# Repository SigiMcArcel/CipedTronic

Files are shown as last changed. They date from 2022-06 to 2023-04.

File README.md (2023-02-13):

#  feasibility study. Bicycle Speedometer
Hardware and software for measuring distance of a bike with a mobil phone.
The needed information will get thru the sine wave of the hub dynamo of the bike.
A hardware converts the sine wave to a TTL signal. 
A microcontroller counts the pulses
The mobil gets the data thru Bluetooth LE
A java app receive the Bluetooth LE data and shows the value on a GUI
The hardware must be simple and small for covering in a bicycle lamp.

#The Application
The microcontroller sends the 

count of pulses (distance), 
the count of pulses per second (velocity)
the count of pulses per second average
the count of pulses per second maximum
The count of pulses will save in the microcontrollers EEPROM

The Android App calculates the informations to Km/h and Km with settings like pulses per revolution and wheel radius,
this data will show in the GUI.

In the first Version i implemented the nordic UART Service and send and receive the data as string.
In the further versions i used a custom service and characteristics to exchange the data.So i spent code and was more comfortable to handle it 

The next idea is to use the standard Bluetooth LE service "Cycling Speed and Cadence" to exchange the data.
So i can use my speedometer with other android Apps.
Therfore i have to reimplement the the pulse measuring.

further steps are :
- Porting the software to a seed XIAO ESP32C3 is lot smaller and has akku load functions
- Combine the hardware with LED Lightning and Supercaps
- extend the android app with "Tours" functionality. So i can set several tours.

##Hardware Komponents
ATMEGA 32u4 Arduino Leonard0
Adafruit nrf80001 breakout
Samsung X-Cover Pro Smartphone Android SDK 30

#Developer Tools
Microchip studio for ATMEGA 32u4
Android studio for Android App developing
LT Spice for developing the Converter Hardware

## Hardware for pulse converting
The big Problem is to handle the voltage on unloaded state.
The voltage can gos up to > 20 Volts.

I'm still looking for a good and sinmplesolution for this problem

##Software
###Microcontroller
Project : CipedTronicMCU
The Software uses fololowing sources:
the nordic nrf80001 sdk
The USB CDC from J. Fiene & J. Romano https://github.com/PennRobotics/acrobot 

USBSerial:
For debugging i implemented a Modul for receive and send string and chars thru the usb interface of the ATMEGA 32u4.
Therfore i'm using the USBDCD source.

Bluetooth LE:
The Atmega 32u4 communicate thru SPI with the Bluetooth LE Breakout.
In the modul BLE.cpp all needed step are implemented for using the breakout.
The nordic sdk includes the necessary functions.
BLE.cpp is written in c++ for compatibility to the nordic sdk.

Evaluate the sine waves of the hub dynamo:
For that i use the counter 1 of the Atmega 32u4. it is count the pulses.
For prevent the overflow after 16 Bit, the software adds the actual counter value to a 32 bit variable and deletes the counter.
Every second the software checks the count of pulses since last call ang gives the count of pulses per second (Counter.c ,Timer.c)

maximum km's:
(Unloaded)
wheel radius = 37 cm, pulses per revolution = 18
circumference per revolution = 2 * 0,00037 kilometers * pi =    0,00232477856 kilometers
pulses per km = 1/0,00232477856 * 18 = 7742 Pulses
or 0,12915436 meters per puls

u32Bit =  4294967295 /7742 = 554761 km. (less than i thought,may be i need a u64Bit Integer)

accuracy:
depends on tire pressure and wight.
Loaded ->
Assumed 4,5 Bar pressure and 70 kg weight a different of 5 mm
circumference per revolution = 2 * 0,000365 kilometers * pi =    0,00229336263 kilometers
pulses per km = 1/0,00229336263 * 18 = 7 848 Pulses
or  0,12740903 meters per pulse									 
unloaded <-> loaded ->
6 Pulses -> 76 cm

almost a metre per kilometre. its a lot !!
But I found a test of gps tracker on Internet. Result : Real distance 5Km , gps tracker 5,14 km.
the speedometer  calculates :  5 km -> 5 * 76 cm = 380 cm. Maybe better.

###Android App
The App is implemented as a Viewmodel Pattern.
The BLE part is implemented fully asynchron. 
Actually the BLE part is written as a singleton class. But it prepared for using as Android service.
The data exchange between class and Viewmodel works with events and livedata.
GUI:
The App consists three Fragments there's is collected as tabs.
Main and Datafragments :
- Shows the velocity and distance
- Resets the counter
Devicefragment:
- Searching and select cipedtronic devices
Settingsfragment:
- Sets wheel raduis and pulses per revolution

classes:
BLEDevice.java : Consist the BLE Stack with all needed functionality.
CipedTronicMCU.java : Opens BLE services,handle characteristics, calculate mcu data
PageViewModel.java : handles data exchange beetween Fragments, starts the MCU/BLE Part

SectionsPagerAdapter.java : Handles Tabs and Fragments
DataFragment.java : The data GUI
DeviceFragment.java : The device search fragment
SettingsFragment.java : The settings fragment

#Branches:
##main
BLE Uart Version of Cipedtronic
##BLENonUart
 the CUstom and standard service

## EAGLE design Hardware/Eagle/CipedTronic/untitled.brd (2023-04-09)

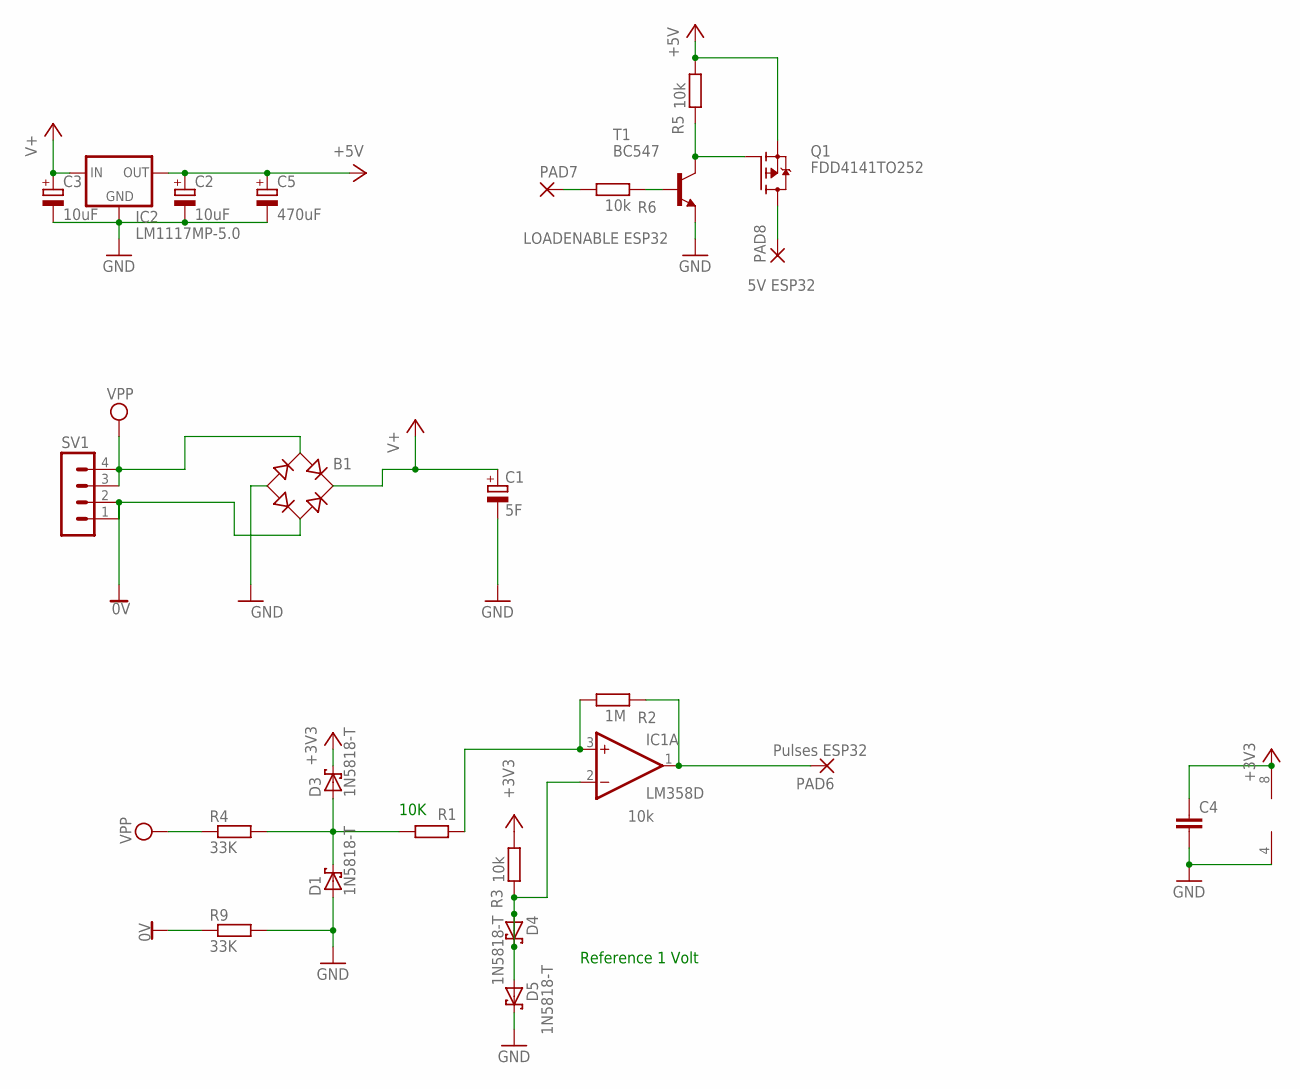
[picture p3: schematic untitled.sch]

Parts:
B1: B-DIL
C1: 5F; E2,5-6E
C2, C3: 10uF; E2,5-6E
C4: C-EU050-024X044; C050-024X044
C5: 470uF; E2,5-6E
D1, D3, D4, D5: 1N5818-T; DO41-7.6
IC1: LM358D; SO08
IC2: LM1117MP-5.0; SOT223
PAD6: Pulses ESP32; 2,15/1,0
PAD7: LOADENABLE ESP32; 2,15/1,0
PAD8: 5V ESP32; 2,15/1,0
Q1: FDD4141TO252; TO252
R1, R3, R5, R6: 10k; 0204V
R2: 1M; 0204V
R4, R9: 33K; 0204V
SV1: MA04-1
T1: BC547; TO92

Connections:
0V: B1.AC2, R9.1, SV1.1, SV1.2
+3V3: B1.+, C1.+, C4.1, D3.C, IC1.8 (V+), R3.1
+5V: C2.+, C5.+, IC2.2 (OUT), IC2.4 (OUT), Q1.2 (S), R5.1
GND: B1.-, C1.-, C2.-, C3.-, C4.2, C5.-, D1.A, D5.C, IC1.4 (V-), IC2.1 (GND), R9.2, T1.1 (E)
unnamed: IC1.1 (OUT), PAD6.1, R2.2
unnamed: PAD7.1, R6.1
unnamed: R6.2, T1.2 (B)
unnamed: IC1.3 (+IN), R1.1, R2.1
unnamed: D4.A, D4.C, D5.A, IC1.2 (-IN), R3.2
unnamed: Q1.1 (G), R5.2, T1.3 (C)
unnamed: PAD8.1, Q1.3 (D)
unnamed: D1.C, D3.A, R1.2, R4.2
V+: C3.+, IC2.3 (IN)
VPP: B1.AC1, R4.1, SV1.3, SV1.4

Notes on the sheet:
10K
Reference 1 Volt

Board: 2 copper layers, 25 parts (0 on the bottom side), 14 nets, no tracks yet.

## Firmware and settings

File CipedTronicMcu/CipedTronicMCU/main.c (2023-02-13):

/* Copyright 2023 Marcel Siegwart
* 
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
* Neither the name of the copyright holders nor the names of
* contributors may be used to endorse or promote products derived
* from this software without specific prior written permission.
* 
* THE SOFTWARE IS PROVIDED "AS IS", WITHOUT WARRANTY OF ANY KIND, 
* EXPRESS OR IMPLIED, INCLUDING BUT NOT LIMITED TO THE WARRANTIES OF MERCHANTABILITY, 
* FITNESS FOR A PARTICULAR PURPOSE AND NONINFRINGEMENT. 
* IN NO EVENT SHALL THE AUTHORS OR COPYRIGHT HOLDERS BE LIABLE FOR ANY CLAIM, 
* DAMAGES OR OTHER LIABILITY, WHETHER IN AN ACTION OF CONTRACT, 
* TORT OR OTHERWISE, ARISING FROM, OUT OF OR IN CONNECTION WITH THE SOFTWARE 
* OR THE USE OR OTHER DEALINGS IN THE SOFTWARE.
*/

/*
 * main.c
 *
 * Main Entry
 * Created: 18.04.2022 13:50:13
 *  Author: Siegwart
 */ 
#include <avr/io.h>
#include <avr/interrupt.h>
#include "Platform/Timer.h"
#include "Platform/GPIO.h"
#include "Platform/Counter.h"
#include "Platform/Serial.h"
#include "CipedTronic/BLE.h"
#include <stdio.h>
#include <stdlib.h>
#include <string.h>


#define SOFTWAREVERSION "00.00.42"
#define DEVICENAME "CIPBLA"

//notification intervall
static volatile uint32_t _LastTimerTick = 0;
static volatile uint32_t _Delay = 0;
static volatile uint32_t _Control = 0;
static volatile uint32_t _Test = 0;

//Speedometer data
static uint32_t _Counter = 0;
static uint32_t _CounterPerSecond = 0;
static uint32_t _CounterPerSecondAvg = 0;
static uint32_t _CounterPerSecondMax = 0;

static void BLERxCallback(uint8_t characteristic, uint32_t value);


//BLE stack callback
static void BLERxCallback(uint8_t characteristic, uint32_t value)
{
	SerialPuts("BLERxCallback ");
	SerialPutsLong(characteristic);
	SerialPuts(" ");
	SerialPutsLong(value);
	SerialPuts("\r\n");
	switch(characteristic)
	{
		//sets Counter Per Second maximum (for future use, multiple tours)
		case PIPE_CIPEDTRONIC_BIKE_SERVICE_MAXIMUM_VELOCITY_RX:
		{
			CounterSetMaxCounterPerSecond(value);
			break;
		}
		//sets Counter Per Second average (for future use, multiple tours)
		case PIPE_CIPEDTRONIC_BIKE_SERVICE_AVERAGE_VELOCITY_RX:
		{
			CounterSetAvgCounterPerSecond(value);
			break;
		}
		//sets Distance (for future use, multiple tours)
		case PIPE_CIPEDTRONIC_BIKE_SERVICE_DISTANCE_RX:
		{
			CounterSetCounter(value);
			break;
		}
		
		//Handles control value
		case PIPE_CIPEDTRONIC_BIKE_SERVICE_CONTROL_RX:
		{
			_Control = value;
			SerialPuts("PIPE_CIPEDTRONIC_BIKE_SERVICE_CONTROL_RX 0x");
			SerialPutsHex32(_Control);
			SerialPuts("\r\n");
			//resets all Counters
			if((_Control & 0x0000001) > 0)
			{
				SerialPuts("Counter Reset\r\n");
				CounterResetCounter();
			}
			_Control = 0;
			break;
		}
	}
}

int main (void)
{
	//initialize mcu hardware
	GPIOInit();
	TimerInit();
	CounterInit();
	USBSerialInit();

	GPIOSetDirection(5,&DDRD,GPIO_DIR_OUT);//tx
	GPIOSetDirection(0,&DDRB,GPIO_DIR_OUT);//rx
	GPIOSetDirection(7,&DDRC,GPIO_DIR_OUT);//PW led
	
	//register Notification Values
	BLERegisterNotificationValue(PIPE_CIPEDTRONIC_BIKE_SERVICE_VELOCITY_TX,&_CounterPerSecond);
	BLERegisterNotificationValue(PIPE_CIPEDTRONIC_BIKE_SERVICE_MAXIMUM_VELOCITY_TX,&_CounterPerSecondMax);
	BLERegisterNotificationValue(PIPE_CIPEDTRONIC_BIKE_SERVICE_AVERAGE_VELOCITY_TX,&_CounterPerSecondAvg);
	BLERegisterNotificationValue(PIPE_CIPEDTRONIC_BIKE_SERVICE_DISTANCE_TX,&_Counter);
	BLEInit(0,100,DEVICENAME,SOFTWAREVERSION,BLERxCallback);
	
	while(1)
	{
		uint32_t tick = TimerGetTick();
		uint32_t diff = tick - _LastTimerTick;
		CounterHandler();//Process Counters
		BLEProcess(); //Process BLE
		if(diff >= 500)
		{
			//Toggle LED
			GPIOToggle(7,&PORTC);
			//Update counter values
			_CounterPerSecond = CounterGetCounterPerSecond();
			_CounterPerSecondMax = CounterGetMaxCounterPerSecond();
			_CounterPerSecondAvg = CounterGetAvgCounterPerSecond();
			_Counter = CounterGetCounter();
			//Send registered notification
			BLESendNotification();
			_LastTimerTick = tick;
		}
		
	}
}

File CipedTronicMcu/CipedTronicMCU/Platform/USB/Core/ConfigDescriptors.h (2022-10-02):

/*
             LUFA Library
     Copyright (C) Dean Camera, 2015.

  dean [at] fourwalledcubicle [dot] com
           www.lufa-lib.org
*/

/*
  Copyright 2015  Dean Camera (dean [at] fourwalledcubicle [dot] com)

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
  The author disclaims all warranties with regard to this
  software, including all implied warranties of merchantability
  and fitness.  In no event shall the author be liable for any
  special, indirect or consequential damages or any damages
  whatsoever resulting from loss of use, data or profits, whether
  in an action of contract, negligence or other tortious action,
  arising out of or in connection with the use or performance of
  this software.
*/

/** \file
 *  \brief USB Configuration Descriptor definitions.
 *  \copydetails Group_ConfigDescriptorParser
 *
 *  \note This file should not be included directly. It is automatically included as needed by the USB driver
 *        dispatch header located in LUFA/Drivers/USB/USB.h.
 */

/** \ingroup Group_StdDescriptors
 *  \defgroup Group_ConfigDescriptorParser Configuration Descriptor Parser
 *  \brief USB Configuration Descriptor definitions.
 *
 *  This section of the library gives a friendly API which can be used in host applications to easily
 *  parse an attached device's configuration descriptor so that endpoint, interface and other descriptor
 *  data can be extracted and used as needed.
 *
 *  @{
 */

#ifndef __CONFIGDESCRIPTORS_H__
#define __CONFIGDESCRIPTORS_H__

	/* Includes: */
		#include "Platform/USB/Common/Common.h"
		#include "USBMode.h"
		#include "HostStandardReq.h"
		#include "StdDescriptors.h"

	/* Enable C linkage for C++ Compilers: */
		#if defined(__cplusplus)
			extern "C" {
		#endif

	/* Preprocessor Checks: */
		#if !defined(__INCLUDE_FROM_USB_DRIVER)
			#error Do not include this file directly. Include LUFA/Drivers/USB/USB.h instead.
		#endif

	/* Public Interface - May be used in end-application: */
		/* Macros: */
			/** Casts a pointer to a descriptor inside the configuration descriptor into a pointer to the given
			 *  descriptor type.
			 *
			 *  Usage Example:
			 *  \code
			 *  uint8_t* CurrDescriptor = &ConfigDescriptor[0]; // Pointing to the configuration header
			 *  USB_Descriptor_Configuration_Header_t* ConfigHeaderPtr = DESCRIPTOR_PCAST(CurrDescriptor,
			 *                                                           USB_Descriptor_Configuration_Header_t);
			 *
			 *  // Can now access elements of the configuration header struct using the -> indirection operator
			 *  \endcode
			 */
			#define DESCRIPTOR_PCAST(DescriptorPtr, Type) ((Type*)(DescriptorPtr))

			/** Casts a pointer to a descriptor inside the configuration descriptor into the given descriptor
			 *  type (as an actual struct instance rather than a pointer to a struct).
			 *
			 *  Usage Example:
			 *  \code
			 *  uint8_t* CurrDescriptor = &ConfigDescriptor[0]; // Pointing to the configuration header
			 *  USB_Descriptor_Configuration_Header_t ConfigHeader = DESCRIPTOR_CAST(CurrDescriptor,
			 *                                                       USB_Descriptor_Configuration_Header_t);
			 *
			 *  // Can now access elements of the configuration header struct using the . operator
			 *  \endcode
			 */
			#define DESCRIPTOR_CAST(DescriptorPtr, Type)  (*DESCRIPTOR_PCAST(DescriptorPtr, Type))

			/** Returns the descriptor's type, expressed as the 8-bit type value in the header of the descriptor.
			 *  This value's meaning depends on the descriptor's placement in the descriptor, but standard type
			 *  values can be accessed in the \ref USB_DescriptorTypes_t enum.
			 */
			#define DESCRIPTOR_TYPE(DescriptorPtr)    DESCRIPTOR_PCAST(DescriptorPtr, USB_Descriptor_Header_t)->Type

			/** Returns the descriptor's size, expressed as the 8-bit value indicating the number of bytes. */
			#define DESCRIPTOR_SIZE(DescriptorPtr)    DESCRIPTOR_PCAST(DescriptorPtr, USB_Descriptor_Header_t)->Size

		/* Type Defines: */
			/** Type define for a Configuration Descriptor comparator function (function taking a pointer to an array
			 *  of type void, returning a uint8_t value).
			 *
			 *  \see \ref USB_GetNextDescriptorComp function for more details.
			 */
			typedef uint8_t (* ConfigComparatorPtr_t)(void*);
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

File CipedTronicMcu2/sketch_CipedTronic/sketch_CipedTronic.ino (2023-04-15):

#include "Ciped.h"
#include "CipedService.h"
#include <BLEDevice.h>
#include <BLEServer.h>

using namespace CipedTronic;
BLEServer* _Server;
Ciped* _Ciped =  NULL;
CipedService* _CipedService = NULL;
uint32_t _LastState = 0;



class CipedControlPointEvents: public CipedTronic::CipedServiceEvents
{
public:
  uint8_t ControlPointWritten(CipedTronic::CipedControlPointOpCodes_e opCode,CipedControlPoint* data)
  {
    if(_Ciped == NULL)
    {
      return (uint8_t)CipedTronic::CipedControlPointResultCodes_e::OperationFailed;
    }
    
    switch(opCode)
    {
      
      case CipedTronic::CipedControlPointOpCodes_e::SetFlags:
      {
        Serial.printf("SetFlags 0x%x\r\n",data->Parameter);
        _Ciped->setFlags(data->Parameter);
        
        return (uint8_t)CipedTronic::CipedControlPointResultCodes_e::Success;
      } 

       case CipedTronic::CipedControlPointOpCodes_e::GetFlags:
      {
  
        data->Parameter = _Ciped->getFlags();
        Serial.printf("GetFlags 0x%x\r\n",data->Parameter);
        return (uint8_t)CipedTronic::CipedControlPointResultCodes_e::Success;
      } 

      case CipedTronic::CipedControlPointOpCodes_e::ResetCounter:
      {
         Serial.printf("ResetCounter 0x%x\r\n",data->Parameter);
        _Ciped->clear();
       return (uint8_t)CipedTronic::CipedControlPointResultCodes_e::Success;
      } 
      
      case CipedTronic::CipedControlPointOpCodes_e::AlarmEnable:
      {
         Serial.printf("AlarmEnable 0x%x\r\n",data->Parameter);
        _Ciped->enableAlarm((bool)data->Parameter);
       return (uint8_t)CipedTronic::CipedControlPointResultCodes_e::Success;
      } 
    }
    
  }
};

void setup() {
  Serial.begin(115200);
  Serial.println("Starting BLE work!");
  

  BLEDevice::init("CIPED");
  _Server = BLEDevice::createServer();
  if(_Server != NULL)
  {
    _Ciped = new Ciped();
    _Ciped->begin();
    _CipedService = new CipedService(_Server,new CipedControlPointEvents());
    _CipedService->start();
  }  

}
 
void loop() {
  CipedBikeData data = {0};
  CipedInfo info = {0};
  uint32_t state = 0;  
  _Ciped->process();
  _Ciped->getCipedBikeData(&data);
  _Ciped->getCipedBikeInfo(&info);
  
  _CipedService->setCipedData(&data);
  _CipedService->setCipedInfo(&info);
  _CipedService->process();
}

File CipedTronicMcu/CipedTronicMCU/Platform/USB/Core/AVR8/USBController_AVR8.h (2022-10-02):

/*
             LUFA Library
     Copyright (C) Dean Camera, 2015.

  dean [at] fourwalledcubicle [dot] com
           www.lufa-lib.org
*/

/*
  Copyright 2015  Dean Camera (dean [at] fourwalledcubicle [dot] com)

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
  The author disclaims all warranties with regard to this
  software, including all implied warranties of merchantability
  and fitness.  In no event shall the author be liable for any
  special, indirect or consequential damages or any damages
  whatsoever resulting from loss of use, data or profits, whether
  in an action of contract, negligence or other tortious action,
  arising out of or in connection with the use or performance of
  this software.
*/

/** \file
 *  \brief USB Controller definitions for the AVR8 microcontrollers.
 *  \copydetails Group_USBManagement_AVR8
 *
 *  \note This file should not be included directly. It is automatically included as needed by the USB driver
 *        dispatch header located in LUFA/Drivers/USB/USB.h.
 */

/** \ingroup Group_USBManagement
 *  \defgroup Group_USBManagement_AVR8 USB Interface Management (AVR8)
 *  \brief USB Controller definitions for the AVR8 microcontrollers.
 *
 *  Functions, macros, variables, enums and types related to the setup and management of the USB interface.
 *
 *  @{
 */

#ifndef __USBCONTROLLER_AVR8_H__
#define __USBCONTROLLER_AVR8_H__

	/* Includes: */
		#include "Platform/USB/Common/Common.h"
		#include "../USBMode.h"
		#include "../Events.h"
		#include "../USBTask.h"
		#include "../USBInterrupt.h"

		#if defined(USB_CAN_BE_HOST) || defined(__DOXYGEN__)
			#include "../Host.h"
			#include "../OTG.h"
			#include "../Pipe.h"
			#include "../HostStandardReq.h"
			#include "../PipeStream.h"
		#endif

		#if defined(USB_CAN_BE_DEVICE) || defined(__DOXYGEN__)
			#include "../Device.h"
			#include "../Endpoint.h"
			#include "../DeviceStandardReq.h"
			#include "../EndpointStream.h"
		#endif

	/* Enable C linkage for C++ Compilers: */
		#if defined(__cplusplus)
			extern "C" {
		#endif

	/* Preprocessor Checks and Defines: */
		#if !defined(__INCLUDE_FROM_USB_DRIVER)
			#error Do not include this file directly. Include LUFA/Drivers/USB/USB.h instead.
		#endif

		#if !defined(F_USB)
			#error F_USB is not defined. You must define F_USB to the frequency of the unprescaled USB controller clock in your project makefile.
		#endif

		#if (F_USB == 8000000)
			#if (defined(__AVR_AT90USB82__) || defined(__AVR_AT90USB162__) || \
			     defined(__AVR_ATmega8U2__) || defined(__AVR_ATmega16U2__) || \
			     defined(__AVR_ATmega32U2__))
				#define USB_PLL_PSC                0
			#elif (defined(__AVR_ATmega16U4__) || defined(__AVR_ATmega32U4__))
				#define USB_PLL_PSC                0
			#elif (defined(__AVR_AT90USB646__)  || defined(__AVR_AT90USB1286__))
				#define USB_PLL_PSC                ((1 << PLLP1) | (1 << PLLP0))
			#elif (defined(__AVR_AT90USB647__)  || defined(__AVR_AT90USB1287__))
				#define USB_PLL_PSC                ((1 << PLLP1) | (1 << PLLP0))
			#endif
		#elif (F_USB == 16000000)
			#if (defined(__AVR_AT90USB82__) || defined(__AVR_AT90USB162__) || \
			     defined(__AVR_ATmega8U2__) || defined(__AVR_ATmega16U2__) || \
			     defined(__AVR_ATmega32U2__))
				#define USB_PLL_PSC                (1 << PLLP0)
			#elif (defined(__AVR_ATmega16U4__) || defined(__AVR_ATmega32U4__))
				#define USB_PLL_PSC                (1 << PINDIV)
			#elif (defined(__AVR_AT90USB646__) || defined(__AVR_AT90USB647__))
				#define USB_PLL_PSC                ((1 << PLLP2) | (1 << PLLP1))
			#elif (defined(__AVR_AT90USB1286__) || defined(__AVR_AT90USB1287__))
				#define USB_PLL_PSC                ((1 << PLLP2) | (1 << PLLP0))
			#endif
		#endif

		#if !defined(USB_PLL_PSC)
			#error No PLL prescale value available for chosen F_USB value and AVR model.
		#endif

	/* Public Interface - May be used in end-application: */
		/* Macros: */
			/** \name USB Controller Option Masks */
			//@{
			/** Regulator disable option mask for \ref USB_Init(). This indicates that the internal 3.3V USB data pad
			 *  regulator should be disabled and the AVR's VCC level used for the data pads.
			 *
			 *  \note See USB AVR data sheet for more information on the internal pad regulator.
			 */
			#define USB_OPT_REG_DISABLED               (1 << 1)

			/** Regulator enable option mask for \ref USB_Init(). This indicates that the internal 3.3V USB data pad
			 *  regulator should be enabled to regulate the data pin voltages from the VBUS level down to a level within
			 *  the range allowable by the USB standard.
			 *
			 *  \note See USB AVR data sheet for more information on the internal pad regulator.
			 */
			#define USB_OPT_REG_ENABLED                (0 << 1)

			/** Option mask for \ref USB_Init() to keep regulator enabled at all times. Indicates that \ref USB_Disable()
			 *  should not disable the regulator as it would otherwise. Has no effect if regulator is disabled using
			 *  \ref USB_OPT_REG_DISABLED.
			 *
			 *  \note See USB AVR data sheet for more information on the internal pad regulator.
			 */
			#define USB_OPT_REG_KEEP_ENABLED           (1 << 3)

			/** Manual PLL control option mask for \ref USB_Init(). This indicates to the library that the user application
			 *  will take full responsibility for controlling the AVR's PLL (used to generate the high frequency clock
			 *  that the USB controller requires) and ensuring that it is locked at the correct frequency for USB operations.
			 */
			#define USB_OPT_MANUAL_PLL                 (1 << 2)

			/** Automatic PLL control option mask for \ref USB_Init(). This indicates to the library that the library should
			 *  take full responsibility for controlling the AVR's PLL (used to generate the high frequency clock
			 *  that the USB controller requires) and ensuring that it is locked at the correct frequency for USB operations.
			 */
			#define USB_OPT_AUTO_PLL                   (0 << 2)
			//@}

			#if !defined(USB_STREAM_TIMEOUT_MS) || defined(__DOXYGEN__)
				/** Constant for the maximum software timeout period of the USB data stream transfer functions
				 *  (both control and standard) when in either device or host mode. If the next packet of a stream
				 *  is not received or acknowledged within this time period, the stream function will fail.
				 *
				 *  This value may be overridden in the user project makefile as the value of the
				 *  \ref USB_STREAM_TIMEOUT_MS token, and passed to the compiler using the -D switch.
				 */
				#define USB_STREAM_TIMEOUT_MS       100
			#endif
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

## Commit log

2022-06-14 Android App: - Settings page added - Tour page added - Bugfix crash in timer run()
2022-06-23 - Changed to atmega32u4 - USB CDC added - Timer calibrated
2022-10-02 missed file added (usb,eeprom routines)
    [ConfigDescriptors.h, Descriptors.h, EndpointStream.h]
2022-12-27 Add missing hedaer file
    [BLE.cpp, main.c]
2022-12-27 Better protocoll implemented Clean up Not tested too high memory usage. has to be improved
    [main.c]
2023-01-04 - rebuild the app without Serial service - cleanups - testing with device
2023-01-04 missing new java files added
    [BLE.cpp, USBSerial.c]
2023-01-08 Error handling while invalid Bluetooth addresses fixed. SettingsFragment : Bluetooth address must be read only Settings -> Changes will write immediately to CipedtronicMCU class Device Fragment -> Ch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
2023-02-13 migration to seed xaio esp32
    [untitled.brd, untitled.sch]
2023-02-22 Cipedtronic with esp32
    [untitled.brd, untitled.sch]
2023-02-26 Rename sketch Extend Timer Add namespace
    [untitled.brd, untitled.sch]
2023-04-09 battery load functionality Radius distance sensor
2023-04-09 battery load functions distance sensor improved pulse formatting
    [untitled.brd, untitled.sch]
2023-04-15 Powersave handling save data in RTC RAM Info characteristic
